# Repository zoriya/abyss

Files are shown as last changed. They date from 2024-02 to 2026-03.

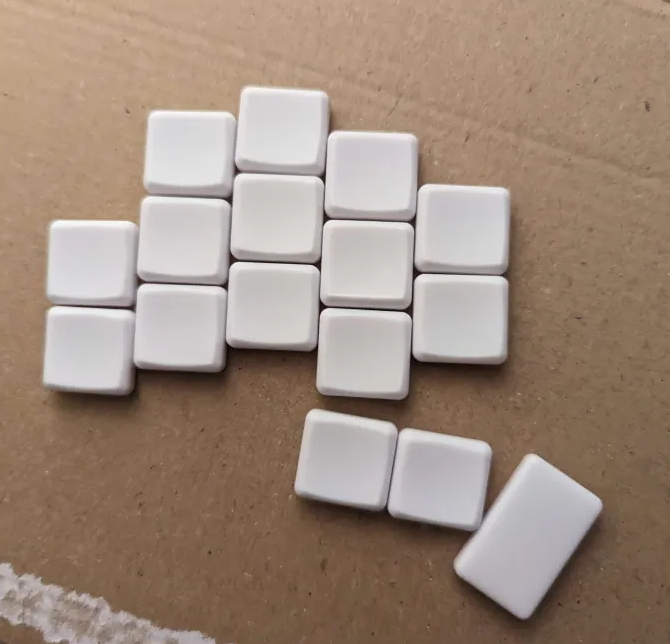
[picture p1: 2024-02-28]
screens/first-cardboard.png

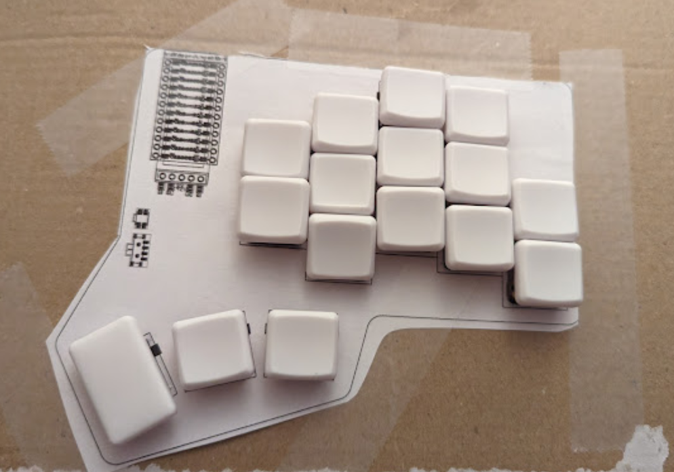
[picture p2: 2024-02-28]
screens/cardboard.png

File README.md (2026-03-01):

# Abyss

A 32 key split keyboard with a low pinky column.

## Components

| Count | Part name | Size/Remark |
| :---: | :---  | :--- |
| 2x  | [Seeed Xiao nRF54L15 - mcu](https://www.seeedstudio.com/XIAO-nRF54L15-p-6493.html) | |
| 2x  | [1208YD - reset button](https://fr.aliexpress.com/item/1005003938985112.html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) | 6x6x7mm |
| 2x  | [401030 Li-Po Battery](https://www.ebay.com/itm/171812433827) | 4x10x30mm |
| 2x  | [SM02B-SRSS-TB - battery connector](https://www.jst-mfg.com/product/pdf/eng/eSH.pdf) | |
|  32x  | choc switch | i use [sunsets](https://lowprokb.ca/products/sunset-tactile-choc-switches) |
|  30x  | 1u choc keycaps | i use [pom](https://splitkb.com/products/moergo-pom-mbk-profile-keycaps?variant=42898367152387) |
| 2x  | 1.5u choc keycaps | i use [pom](https://splitkb.com/products/moergo-pom-mbk-profile-keycaps?variant=42898363121923) |
|  32x  | [hotswap chock sockets](https://chosfox.com/products/kailh-choc-switch-1350-hot-swap-sockets?_pos=1&_sid=94423b5bb&_ss=r) | |
|  32x  | diodes | |
|  16x  | magnets | [20x8x1.5mm](https://www.amazon.fr/dp/B0DDCVJTG8?th=1) |
| 4x  | m2 screws | 4/6/8mm |
| 4x  | m2 standoff | [<5mm wide, 6mm height](https://www.aliexpress.us/item/3256804230166399.html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)|

## Info

Case dimensions:
 - height: 10.5mm -> 1.6mm (pcb) + 3.1mm (hotswap socket) + 5.5mm (choc size on top of the pcb)
 - length: 115.38mm
 - width: 96.25mm

Transport case dimesions:
- height: 30mm (2x2mm for enclosure, 2x10.5mm for keyboard, 5mm in middle for keycaps + gap)
- length: 124.35mm
-  width: 105.25mm

## Keymap

keymap

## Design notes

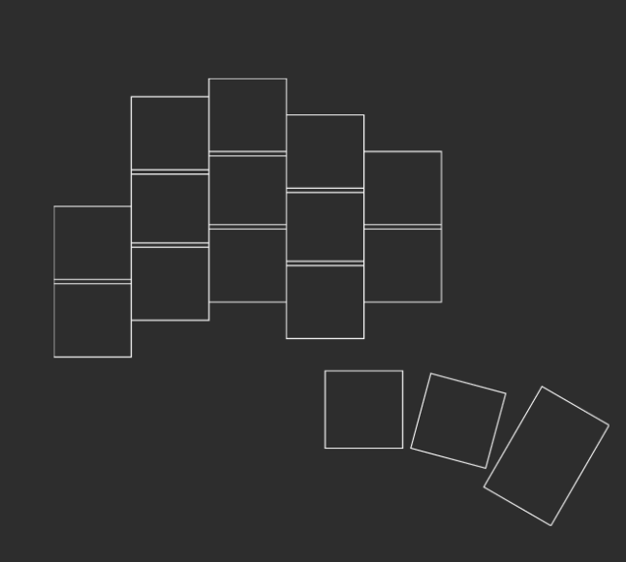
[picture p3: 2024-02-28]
screens/ergogen-outlines.png

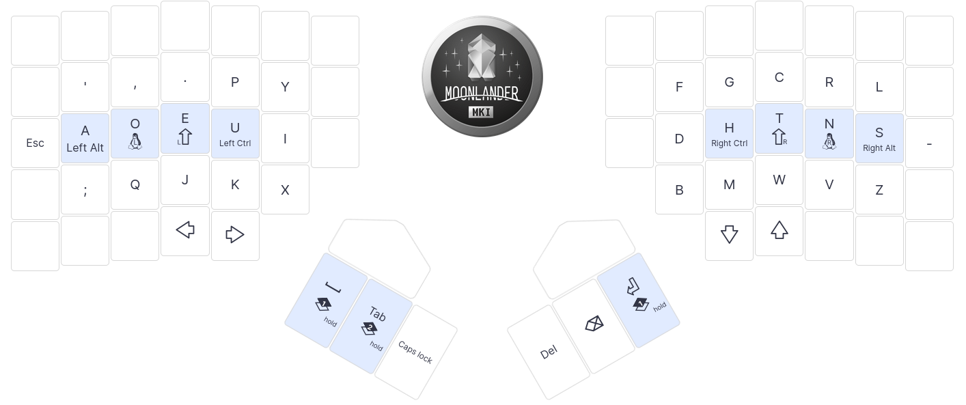
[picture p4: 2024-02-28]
screens/moonlander-layout.png

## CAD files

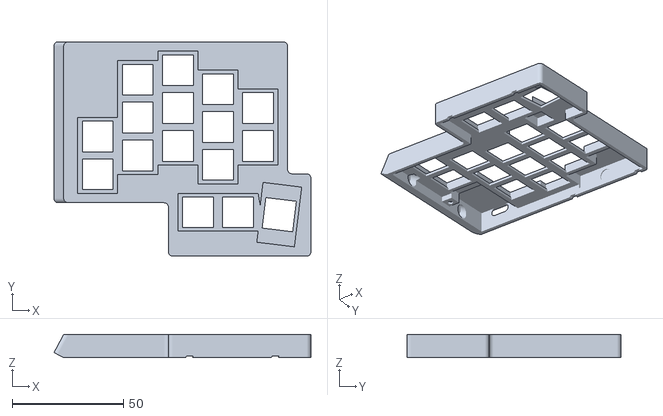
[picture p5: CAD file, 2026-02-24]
case/case-Top.stl
115.4 x 96.2 x 10.5

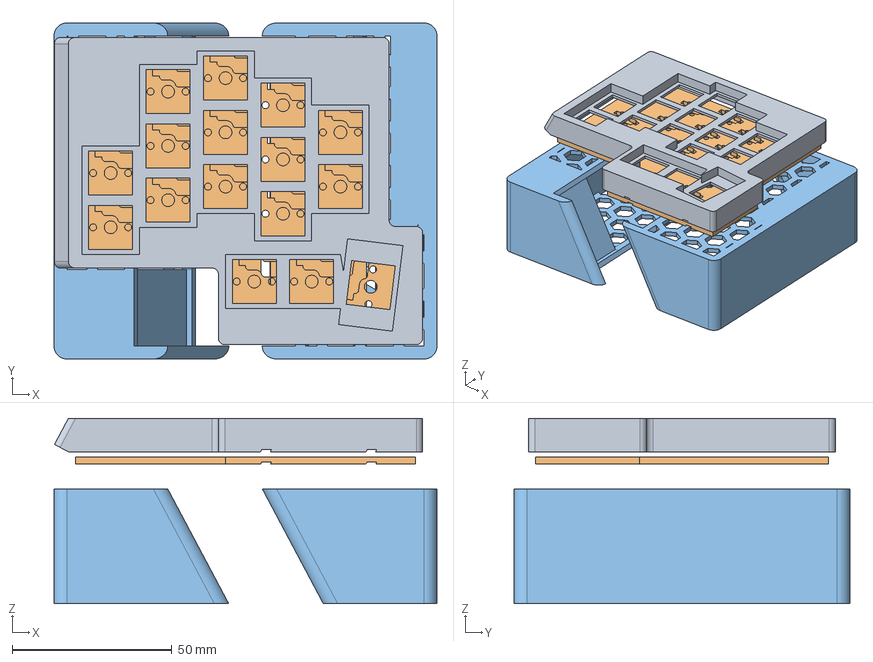
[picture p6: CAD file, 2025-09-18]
case/case.FCStd
120.0 x 105.2 x 58.1 mm
Top
Bottom
Case

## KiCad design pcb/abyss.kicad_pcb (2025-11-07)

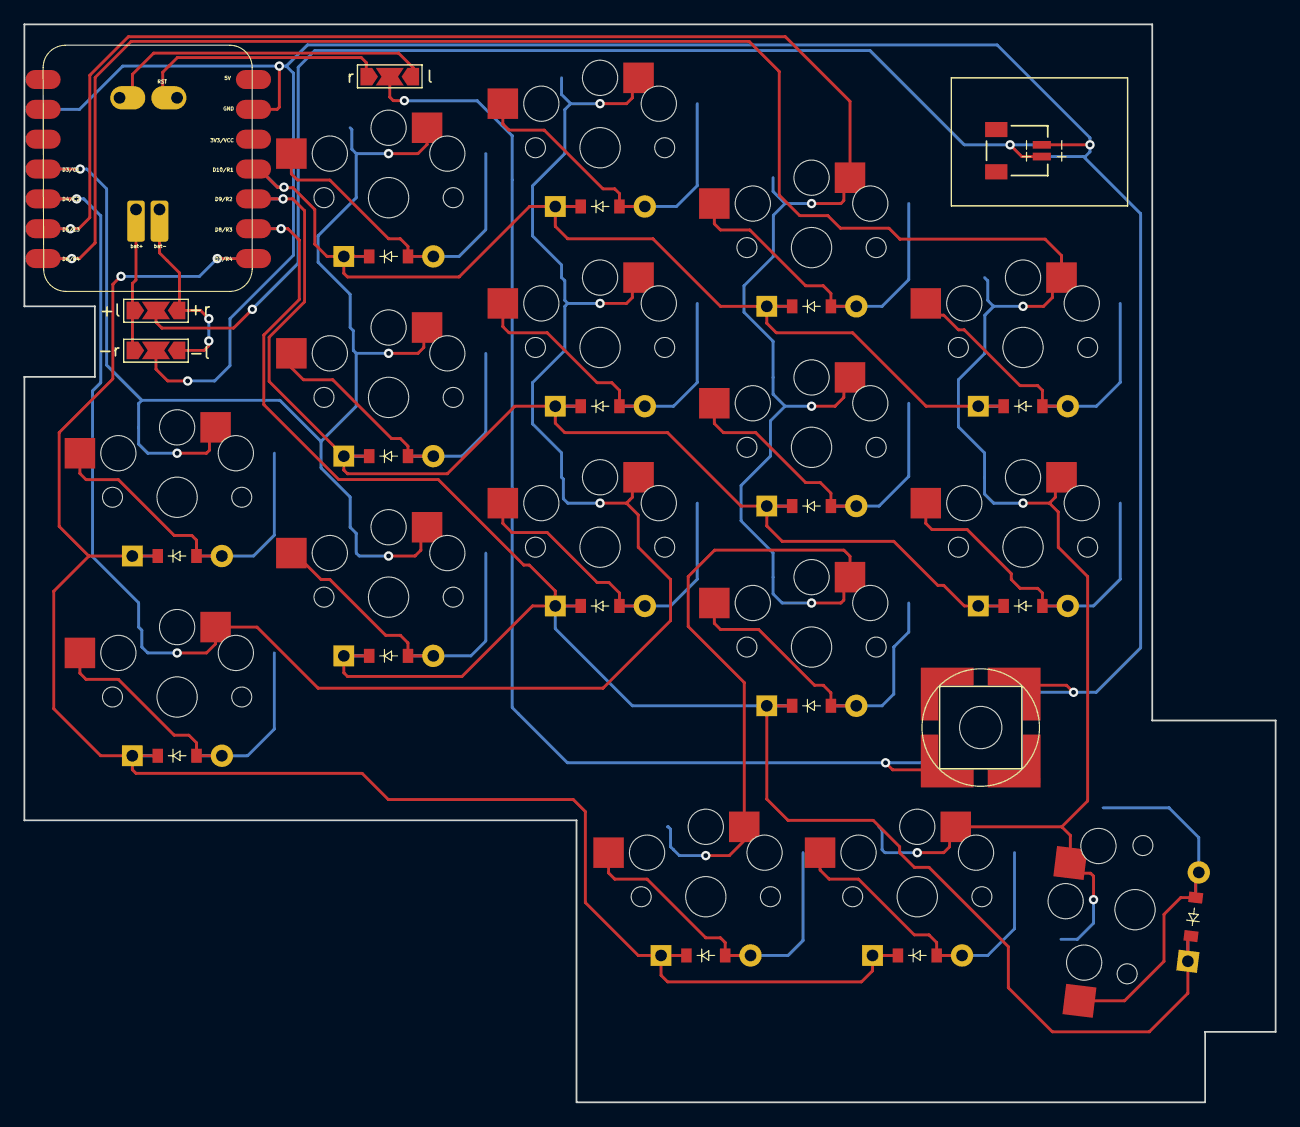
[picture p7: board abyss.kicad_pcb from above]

Board: 2 copper layers, 106.5 x 91.8 mm, 32 parts (0 on the bottom side), 24 nets.

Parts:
D1, D2, D3, D4, D5, D6, D7, D8, D9, D10, D11, D12, D13, D14, D15, D16: ComboDiode
S1, S2, S3, S4, S5, S6, S7, S8, S9, S10, S11, S12, S13, S14, S15, S16: PG1350

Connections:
C1: S2.1, S3.1, S4.1, S5.1
C2: S1.1, S6.1, S7.1, S8.1
C3: S9.1, S10.1, S11.1, S14.1
C4: S12.1, S13.1, S15.1, S16.1
R1: D5.1, D8.1, D11.1, D13.1
R2: D4.1, D7.1, D10.1, D12.1
R3: D3.1, D6.1, D9.1, D16.1
R4: D1.1, D2.1, D14.1, D15.1
home_cluster: D15.2, S15.2
index_bottom: D9.2, S9.2
index_home: D10.2, S10.2
index_top: D11.2, S11.2
inner_bottom: D12.2, S12.2
inner_home: D13.2, S13.2
left_cluster: D14.2, S14.2
middle_bottom: D6.2, S6.2
middle_home: D7.2, S7.2
middle_top: D8.2, S8.2
pinky_bottom: D1.2, S1.2
pinky_home: D2.2, S2.2
right_cluster: D16.2, S16.2
ring_bottom: D3.2, S3.2
ring_home: D4.2, S4.2
ring_top: D5.2, S5.2

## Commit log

2024-02-04 Use square outlines and start pcb
    [abyss.kicad_pcb, abyss.kicad_sch]
2024-02-06 Add infused kim footprints
2024-02-06 Fix oled pos
    [abyss.kicad_pcb]
2024-02-06 Add reset and power switch
    [abyss.kicad_pcb]
2024-02-06 Rotate reset/power switches
    [abyss.kicad_pcb]
2024-02-07 Add keys and oled routing hints
    [abyss.kicad_pcb]
2024-02-07 Fix extra column in routing
    [abyss.kicad_pcb]
2024-02-14 Fix nets
    [abyss.kicad_pcb]
2024-02-15 Remove nice view footprint
2024-02-19 Add battery jst and cleanup layout
    [abyss.kicad_pcb]
2024-02-19 Move jst connector at the top
    [abyss.kicad_pcb]
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2024-02-20 Add mounting holes on the pcb
    [abyss.kicad_pcb]
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2024-02-20 Add mounting holes for the plate on the pcb
    [abyss.kicad_pcb]
2024-02-20 Route pcb
    [abyss.kicad_pcb]
2024-02-28 Finish pcb routing
    [abyss.kicad_pcb]
2024-02-28 Add plate pcb
    [abyss.kicad_pcb, plate.kicad_pcb]
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2024-04-07 Move boards to config foldre
2024-04-07 Move metadata file to boards/shield folder
2024-04-10 Fix bracket combo
2024-04-11 Add directions keys and esc combo
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2024-07-14 Init FreeCad case project
    [case.FCStd]
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2024-08-23 Add reset on both sides
    [abyss.step, case.FCStd]
2024-09-12 Case top start
    [case.FCStd, case2.FCStd]
2024-09-12 Add mc pin holes
    [case2.FCStd]
2024-09-13 Add walls and usb hole
    [case2.FCStd]
2024-09-13 Add fillets
    [case2.FCStd]
2024-09-13 Add inner fillets
    [case2.FCStd]
2024-09-13 Add screw holes
    [case2.FCStd]
2024-09-13 wip fix sketches
    [case2.FCStd]
2024-09-13 fix sketches part 2
    [case2.FCStd]
2024-09-14 wip wall part2
    [case2.FCStd]
2024-09-14 Restart case and make clean sketches
    [case.FCStd]
2024-09-14 Correct sketches placements
    [case.FCStd]
2024-09-14 Create bottom lid
    [case.FCStd]
2024-09-14 Add screw holes in bottom lid
    [case.FCStd]
2024-09-15 Make better bottom
    [case.FCStd, case3.FCStd]
2024-09-15 Better tolerances
    [case.FCStd]
2024-09-16 Add walls
    [case.FCStd]
2024-09-16 Add inner walls
    [case.FCStd]
2024-09-16 Correct inner wall
    [case.FCStd]
2024-09-16 Add screw holes in wall (part 1)
    [case.FCStd]
2024-09-17 Allign screw holes
    [case.FCStd]
2024-09-17 Fillet bottom walls
    [case.FCStd]
2024-09-17 Add key holes
    [case.FCStd]
2024-09-18 Add mc hole
    [case.FCStd]
2024-09-18 Better mc distances
    [case.FCStd]
2024-09-18 Add inner keys hole sketch
    [case.FCStd]
2024-09-18 Finish key hole sketch
    [case.FCStd]
2024-09-18 Add key hole
    [case.FCStd]
2024-09-18 Fix flipped constraints
    [case.FCStd, case2.FCStd]
2024-09-18 Fix recompute issues
    [case.FCStd]
2024-09-18 Add missing screw holes
    [case.FCStd]
2024-09-18 Add usb hole sketch
    [case.FCStd]
2024-09-18 Add usb hole
    [case.FCStd]
2024-09-19 Add nut holes
    [case.FCStd]
2024-09-19 Remove corners for nut holes
    [case.FCStd]
2024-09-22 Add feet holes
    [case.FCStd]
2024-09-23 Add feets
    [case.FCStd]
2024-09-23 Remove old case tries
    [case2.FCStd, case3.FCStd]
2024-09-27 Draft feets
    [case.FCStd]
2024-09-27 Make nut slot smaller
    [case.FCStd]
2024-09-27 Remake lid
    [case.FCStd]
2024-09-27 Properly allign screw holes
    [case.FCStd]
2024-09-29 Add nut shape in holes
    [case.FCStd]
2024-09-29 Add the orchid on the surface
    [case.FCStd]
2024-09-29 Add tolerence for feets
    [case.FCStd]
2024-09-29 Fix spacing
    [case.FCStd]
2024-09-30 Remove bottom ledge & increment lit tolerence
    [case.FCStd]
2024-09-30 Reduce wall height
    [case.FCStd]
2024-09-30 Increment feet tolerences & height
    [case.FCStd]
2024-10-01 Fix feet magnet pocket height
    [case.FCStd]
2024-10-01 Widen screw holes
    [case.FCStd]
2024-10-03 Update orchid
    [case.FCStd]
2024-10-03 Add slots for nuts
    [case.FCStd]
2024-10-03 Add nut slot covers
    [case.FCStd]
2024-10-06 Fix lid tolerences and rework nut slot
    [case.FCStd]
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2025-04-13 Reverse battery connector
2025-04-13 Remove pcb
    [abyss.kicad_pcb, abyss.kicad_sch, abyss.step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]
2025-04-13 Init pcb & add mcu
    [abyss.kicad_pcb, abyss.kicad_sch]
2025-04-14 Add power switch footprint
    [abyss.kicad_pcb]
2025-04-17 Restart case
    [case.FCStd]
2025-04-18 Re-rework case
    [case.FCStd, case2.FCStd]
2025-04-18 Move case2 to case
    [case.FCStd, case2.FCStd]
2025-04-18 Add key cutout
    [case.FCStd]
2025-04-18 Try to fix distances
    [case.FCStd]
2025-04-18 Fix thumb key
    [case.FCStd]
2025-04-18 Add battery slot
    [case.FCStd]
2025-08-17 Fix case height
    [case.FCStd]
2025-08-17 Fix tolerences
    [abyss.kicad_pcb, case.FCStd]
2025-08-18 Add socket holes
    [case.FCStd]
2025-08-18 Move usb hole to bottom
    [case.FCStd]
2025-08-18 wip: Create transport case
    [case.FCStd]
2025-08-18 Add honeycomb for case
    [case.FCStd]
2025-08-18 Open case in two
    [case.FCStd]
2025-08-18 Add case stands
    [case.FCStd]
2025-08-18 Start feet slips
    [case.FCStd]
2025-08-19 Add feet slips on case
    [case.FCStd]
2025-08-19 Pad case to fit keyboard correctly
    [case.FCStd]
2025-08-20 Fix socket hole
    [case.FCStd]
2025-08-20 Add m2 holes to fix bottom & top
    [case.FCStd]
2025-08-20 Make case more square
    [case.FCStd]
2025-08-20 Add case side stands
    [case.FCStd]
2025-08-20 Fix pcb size
    [abyss.kicad_pcb, case.FCStd]
2025-08-20 Fix transport case cuttout
    [case.FCStd]
2025-08-20 Transport case gap
    [case.FCStd]
2025-08-20 Reinit pcb
    [abyss.kicad_pcb, abyss.kicad_sch]
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2025-08-25 wip: Fix case angle
    [case.FCStd]
2025-08-26 Fix case angle
    [case.FCStd]
2025-08-26 Cleanup case
    [case.FCStd]
2025-08-26 Use 4mm walls for transport case
    [case.FCStd]
2025-08-26 wip: Better case
    [case.FCStd]
2025-08-26 wip: Pcb
    [abyss.kicad_pcb]
2025-08-26 Fix angles
    [abyss.kicad_pcb, case.FCStd]
2025-08-26 Cleanup fillets
    [case.FCStd]
2025-08-26 Add magnet holes
    [case.FCStd]
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2025-08-26 Add reset button to pcb
    [abyss.kicad_pcb]
2025-08-26 Add through hole for reset btn
    [abyss.kicad_pcb]
2025-08-26 wip: Add m2 holes in pcb
    [abyss.kicad_pcb]
2025-08-30 Cleanup footprints
    [abyss.kicad_pcb]
2025-08-30 Start to name nets
    [abyss.kicad_pcb]
2025-08-30 Fix netnames of all keys
    [abyss.kicad_pcb]
2025-08-31 Route gnd & 5v
    [abyss.kicad_pcb]
2025-08-31 Route most keys
    [abyss.kicad_pcb]
2025-08-31 Route everything
    [abyss.kicad_pcb]
2025-08-31 Move magnets
    [abyss.kicad_pcb]
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2025-08-31 Center magnet in case stand
    [abyss.kicad_pcb]
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2025-08-31 Cleanup material list
    [abyss.kicad_pcb]
2025-09-01 Remake m2 standoff holes
    [abyss.kicad_pcb]
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2025-09-03 Add tri jumper
    [abyss.kicad_pcb]
2025-09-03 Fix warnings
    [abyss.kicad_pcb]
2025-09-04 Finish pcb
    [abyss.kicad_pcb]
2025-09-18 Fix some case issues
2025-09-18 Fix magnet hole placements
2025-09-18 Angle slit
    [case.FCStd]
2025-09-20 Fix m2 holes and standoff
2025-09-20 Fix case size
2025-09-20 Fix usb hole placement
2025-09-21 Fix holes in top
2025-09-22 Fix magnets in case
2025-10-26 Cleanup mc hole & magnet holes
    [abyss.kicad_pcb]
2025-10-26 Fix rst btn
    [abyss.kicad_pcb]
2025-10-29 wip: Battery and mc fixes
    [abyss.kicad_pcb]
2025-11-04 Add pcb tri jumper for reset
    [abyss.kicad_pcb]
2025-11-04 Fix case
2025-11-07 Fix resetbtn & bat conn
    [abyss.kicad_pcb]
2025-11-07 Use reflow for mc
    [abyss.kicad_pcb]
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2026-02-24 Fix usb
    [case-Top.stl]
2026-02-26 Fix usb + holes
2026-02-26 Fix case magnets
2026-02-26 Fix stand magnets
2026-02-26 Fix case position
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
